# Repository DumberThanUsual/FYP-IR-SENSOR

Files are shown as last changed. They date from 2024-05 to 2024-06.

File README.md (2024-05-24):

# IR sensor for First Year Project

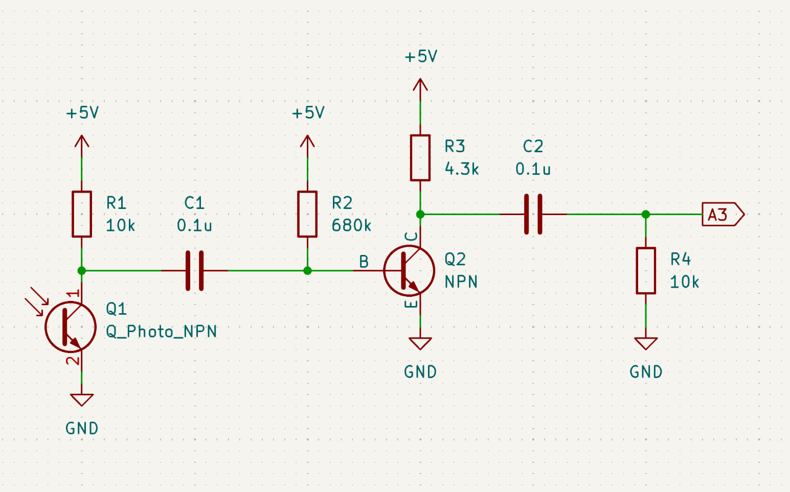
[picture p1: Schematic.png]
Schematic


Circuit output goes to PA04 - A3.
Code is in /src/ - use AC_INT_ONLY for now

The code enables the built in analog comparator and routes PA04 to one of its input, and the internal 1.1V bandap reference to the other. It generates an interrupt on every rising edge of the IR sensor. The frequency is measured in the ISR by using the micros() function.

The other script routes the comparator output to a timer to measure the period without using interrupts but is less accurate for some reason.

## ToE

The IR signal is a PWM signal with ~20µs pulse width and a variable frequency, depending on the species of the lizard.

This light signal is detected by the basic phototransistor supplied with the lab rover kit in a common emitter configuration, which inverts the positive pulses to negative pulses. This is then amplified by ~x5 with a common emitter amplifier after being AC coupled. The output is then a series of amplified positive pulses that are ground referenced and fed into the A3 (PA04) input on the SAMD21 µC.

The amplifier base is biased so that the collector operating point is just above 0V, since the output of interest only swings positive. The gain and tehrefore the sensitivity could be increased by adding an acitve load, and it could be stabilised by adding an emitter resistor. However, these are not important in this design.

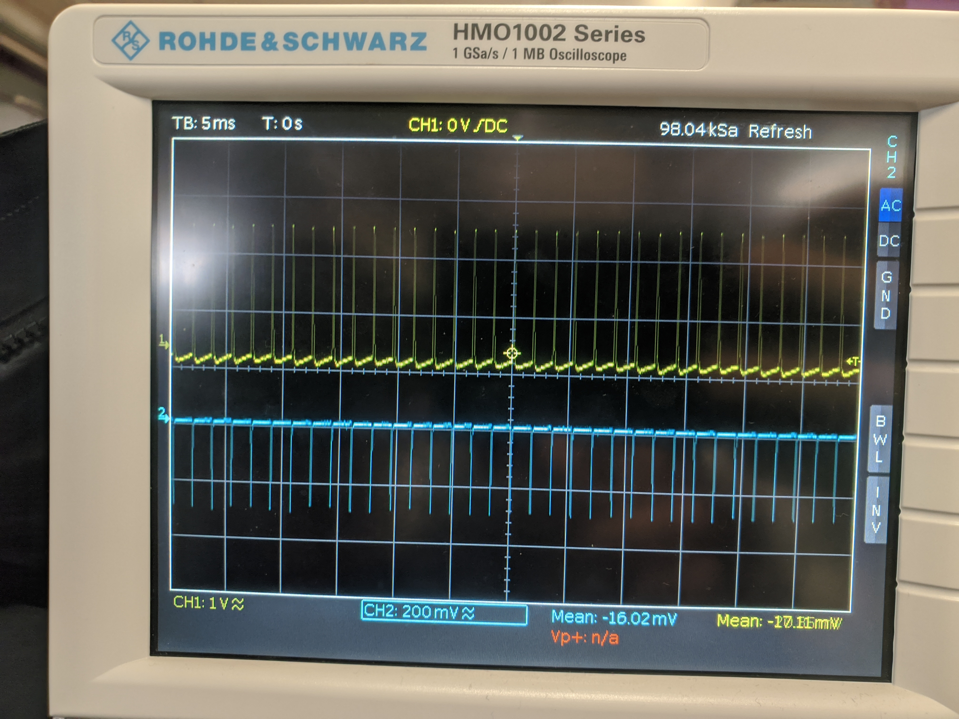
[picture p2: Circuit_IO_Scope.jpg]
Circuit_IO_Scope


```↑ Blue: Collector of the phototransistor, Yellow: Output of the amplfier and input to the µC```

Inside the µC, the AC pin MUX is connected to the AIN0 input of the two integrated analog comparators (AC0), and connected to the positive input of the comparator. The negative input is connected to the internal 1.1V reference. The comparator interrupts are configured to produce a CPU interrupt on every rising edge, where the code measures the time elapsed between pulses and then the frequency.

In one of the designs for the magnetic sensor, a 0.5V reference voltage is reqired to be read by the ADC on startup. Since it is already connected to an analog input, it can be used as the negative input to the AC after it is read by the ADC to improve range.

The range is betweeen varied between 25-30cm depending on external conditions, and is more than enough considering other sensors have a range of < 15 cm.

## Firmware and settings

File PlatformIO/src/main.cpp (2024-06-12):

#include <Arduino.h>
#include "wiring_private.h"

void setup() {

  // Analog comparator (AC) configuration

  // Enable clock sources
  REG_PM_APBCMASK |= PM_APBCMASK_AC; // Enable APB Clock for AC (CLK_AC_APB)
  REG_GCLK_CLKCTRL = GCLK_CLKCTRL_ID_AC_ANA | GCLK_CLKCTRL_CLKEN | GCLK_CLKCTRL_GEN_GCLK0; // Enable comparator analog clock (GCLK_AC_ANA)
  REG_GCLK_CLKCTRL = GCLK_CLKCTRL_ID_AC_DIG | GCLK_CLKCTRL_CLKEN | GCLK_CLKCTRL_GEN_GCLK0; // Enable comparator digital clock (GCLK_AC_DIG)

  //SET PA04 as comparator AIN0
  pinMode(A3, INPUT);
  pinPeripheral(A3, PIO_AC_CLK);

  // Configure comparator 0
  REG_AC_COMPCTRL0 = AC_COMPCTRL_SPEED_HIGH | AC_COMPCTRL_MUXPOS_PIN0 | AC_COMPCTRL_MUXNEG_BANDGAP | AC_COMPCTRL_SWAP | AC_COMPCTRL_INTSEL_RISING | AC_COMPCTRL_HYST | AC_COMPCTRL_FLEN_MAJ5 | AC_COMPCTRL_ENABLE; // Configure and enable comparator 0
  REG_AC_INTENSET = AC_INTENSET_COMP0; // Enable Comparator interrupt for comparator 0
  REG_AC_EVCTRL |= AC_EVCTRL_COMPEO0; // Enable event output for comparator 0
  REG_AC_CTRLA |= AC_CTRLA_ENABLE; // Enable comparators

  NVIC_EnableIRQ (AC_IRQn); // Enable AC interrupts in NVIC

  Serial.begin(115200);
  
}

void loop() {
    
}

unsigned long last = 0;

void AC_Handler (void) {
  unsigned long now = micros();
  Serial.print("RISE: ");
  Serial.println(now-last);
  Serial.print("Freq: ");
  Serial.println(1000000/(now-last));
  last = now;
  REG_AC_INTFLAG |= AC_INTFLAG_COMP0; // Clear interrupt
}

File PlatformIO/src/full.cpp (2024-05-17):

#include <Arduino.h>

void setup() {

  // Event system (EVSYS) configuration

  // Enable clock sources
  REG_PM_APBCMASK |= PM_APBCMASK_EVSYS; // Enable APB clock for EVSYS (CLK_EVSYS_APB)
  REG_GCLK_CLKCTRL = GCLK_CLKCTRL_ID_EVSYS_0 | GCLK_CLKCTRL_CLKEN | GCLK_CLKCTRL_GEN_GCLK0; // Enable generic clock for channel 0 (GCLK_EVSYS_CHANNEL_0)

  // Configure Channel 0
  REG_EVSYS_USER = EVSYS_USER_CHANNEL(1U) | EVSYS_ID_USER_TC4_EVU; // Connnect channel 0 to TC4
  REG_EVSYS_CHANNEL = EVSYS_CHANNEL_CHANNEL(0U) | EVSYS_CHANNEL_EDGSEL_BOTH_EDGES | EVSYS_CHANNEL_PATH_SYNCHRONOUS | EVSYS_CHANNEL_EVGEN(0x44U); // Configure channel source

  // Enbale interrupts for debugging
  REG_EVSYS_INTENSET = EVSYS_INTENSET_EVD0;
  //NVIC_EnableIRQ(EVSYS_IRQn);

  // Timer coutner 4 (TC4) configuration

  //Enable clock sources
  REG_PM_APBCMASK |= PM_APBCMASK_TC4; //Enable APB clock for TC4 (CLK_TC4_APB)
  REG_GCLK_CLKCTRL = GCLK_CLKCTRL_ID_TC4_TC5 | GCLK_CLKCTRL_CLKEN | GCLK_CLKCTRL_GEN_GCLK0; // Enable generic clock for TC4 and TC5 (GCLK_TC4_TC5)

  // Configure TC4
  REG_TC4_CTRLA |= TC_CTRLA_MODE_COUNT16 | TC_CTRLA_WAVEGEN_NFRQ | TC_CTRLA_PRESCALER_DIV8 | TC_CTRLA_PRESCSYNC_PRESC; // Configure CTRLA register
  //REG_TC4_CTRLBSET |= TC_CTRLBSET_ONESHOT;
  REG_TC4_CTRLC |= TC_CTRLC_CPTEN0 | TC_CTRLC_CPTEN1; // Enable capture channels 1 & 2
  REG_TC4_EVCTRL |= TC_EVCTRL_TCEI | TC_EVCTRL_EVACT_PPW;
  REG_TC4_CTRLA |= TC_CTRLA_ENABLE;

  // Analog comparator (AC) configuration

  // Enable clock sources
  REG_PM_APBCMASK |= PM_APBCMASK_AC; // Enable APB Clock for AC (CLK_AC_APB)
  REG_GCLK_CLKCTRL = GCLK_CLKCTRL_ID_AC_ANA | GCLK_CLKCTRL_CLKEN | GCLK_CLKCTRL_GEN_GCLK0; // Enable comparator analog clock (GCLK_AC_ANA)
  REG_GCLK_CLKCTRL = GCLK_CLKCTRL_ID_AC_DIG | GCLK_CLKCTRL_CLKEN | GCLK_CLKCTRL_GEN_GCLK0; // Enable comparator digital clock (GCLK_AC_DIG)

  /*
  // Configure PA18 as comparator output
  pinMode(10, OUTPUT);
  // Register addresses for SAM D21
  *(RwReg*)(0x41004458U) |= PORT_PINCFG_PMUXEN; // Enable MUX
  *(RwReg*)(0x41004439U) |= PORT_PMUX_PMUXE_H; // Set MUX to channel H (AC_COUT0)
  */

  //SET PA04 as comparator AIN0
  pinMode(A3, INPUT);
  // Register addresses for SAM D21 as aliases are not provided
  *(RwReg*)(0x41004444U) |= PORT_PINCFG_PMUXEN; // Enable MUX
  *(RwReg*)(0x41004432U) |= PORT_PMUX_PMUXE_B; // Set MUX to channel B (AC_AIN0)

  // Configure comparator 0
  REG_AC_COMPCTRL0 = AC_COMPCTRL_SPEED_HIGH | AC_COMPCTRL_MUXPOS_PIN0 | AC_COMPCTRL_MUXNEG_BANDGAP | AC_COMPCTRL_SWAP | AC_COMPCTRL_INTSEL_RISING | AC_COMPCTRL_HYST | AC_COMPCTRL_FLEN_MAJ5 | AC_COMPCTRL_ENABLE; // Configure and enable comparator 0
  REG_AC_INTENSET = AC_INTENSET_COMP0; // Enable Comparator interrupt for comparator 0
  REG_AC_EVCTRL |= AC_EVCTRL_COMPEO0; // Enable event output for comparator 0
  REG_AC_CTRLA |= AC_CTRLA_ENABLE; // Enable comparators

  NVIC_EnableIRQ (AC_IRQn);

  Serial.begin(115200);
  
}

void loop() {
  //Serial.println(REG_TC4_COUNT16_CC0);
  //Serial.println(REG_TC4_COUNT16_CC1);
  //Serial.println(REG_TC4_INTFLAG, BIN);
  /*
  if (REG_TC4_INTFLAG >> 1 & 1) {
    Serial.println(6000000/REG_TC4_COUNT16_CC0);
    Serial.println();
  }
  delay(10);
  */
 
}

unsigned long last = 0;

void AC_Handler (void) {
  unsigned long now = micros();
  Serial.print("RISE: ");
  Serial.println(now-last);
  Serial.print("Freq: ");
  Serial.println(1000000/(now-last));
  last = now;
  REG_AC_INTFLAG |= AC_INTFLAG_COMP0;
}

void EVSYS_Handler (void) {
  Serial.print("EVENT TC4 value: ");
  Serial.println(REG_TC4_COUNT16_COUNT);
  Serial.println(REG_TC4_COUNT16_CC0);
  REG_EVSYS_INTFLAG |= EVSYS_INTFLAG_EVD0;
}
